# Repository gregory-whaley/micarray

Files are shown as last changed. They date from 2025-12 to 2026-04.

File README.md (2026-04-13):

# MicArray
Multichannel USB microphone for Raspbery Pi Pico for use in acoustic array beamforming.

This C code and PIO code will accept I2S data from two MEMS microphones and create a USB 2.0 audio microphone source with two channels intially, and expandable to more channels in later versions.  The target MCU is the Raspberry Pi RP2040 on the Pico board and the target microphone is the Invensense ICS-43434 MEMS microphone with I2S interface.  The code supports the following features:

- USB 2.0 device enumerates as a standard audio class 2.0 isochronous streaming device.  No host driver installation is necessary for Windows/Mac/Linux.
- Audio sample rate is fixed at 48000 Hz.
- Data is encoded as PCM samples SE_32 (32 bits per sample).
- Audio volume (gain) is fixed and so volume control must be performed at the host application level.
- MEMS microphone interface is I2S with both outputs interleaved into one data path.
- Target MEMS microphone is Invensense ICS-43434, 24 bits/sample.
- Uses Raspberry Pi Pico RP2040 development board.
- USB enumeration of HID interface providing MCU (environment) temperature and microphone separation distance which are important for acoustic beamforming calculations.

## Documentation

### Hardware
The system can be constructed using a Raspberry Pi Pico development board and two MEMS microphone evaluation boards from Adafruit (Part #6049) as shown in the following diagram.
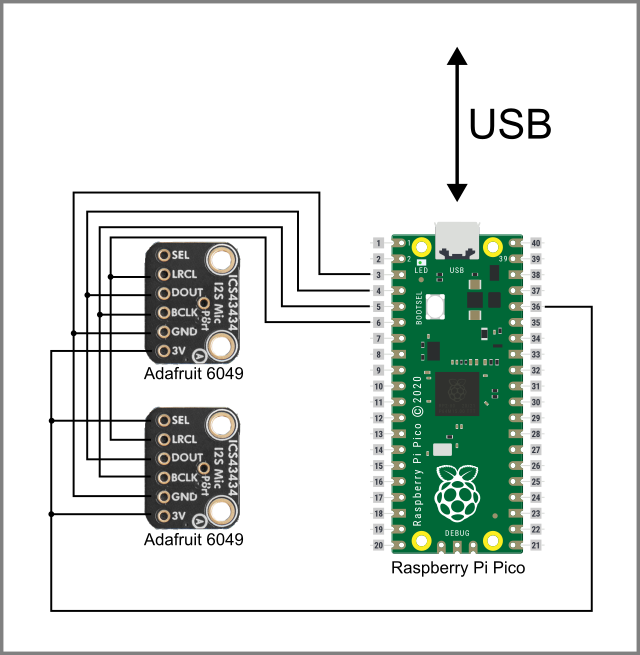
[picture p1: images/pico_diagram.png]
Connection Diagram for Dual Microphones
  Connection Diagram for Dual Microphones

### Supported Boards
- Raspberry Pi Pico/W (RP2040)
- Adafruit #6049 MEMS microphone evaluation board

### Building and Installing

The code is built using the standard [Raspberry Pi Pico SDK](https://github.com/raspberrypi/pico-sdk) and leverages the [TinyUSB library](https://github.com/hathach/tinyusb) for usb functions.

Instructions for installing the Pico development SDK [can be found here](https://rptl.io/pico-get-started).

Clone this repo to a new folder in your local system.
```shell
mkdir micarray
git clone https://github.com/gregory-whaley/micarray.git
```

Unfortunately the version of TinyUSB which is automatically included with the Pico SDK has a buffer allocation error in streaming audio.  This error has been fixed in version 0.19.0, so we must instead clone the current TinyUSB repository also to a separate folder in your local system.
```shell
mkdir tinyusb
git clone https://github.com/hathach/tinyusb.git
```

  The CMakeLists.txt file in the micarray repo includes a redirection to this updated local TinyUSB folder, and so you must edit the following line to point cmake to your local TinyUSB folder.
```
set(PICO_TINYUSB_PATH "/home/YOUR_LOCAL_FOLDER/tinyusb")
```

The code is built from the linux command line as follows:
```shell
cd YOUR_LOCAL_FOLDER/micarray
mkdir build
cd build
cmake .. -DBOARD=raspberry_pi_pico
make
```
which will produce a *.uf2 binary output file in the build folder.  Then follow the standard process to flash the file to the pico by plugging in the pico with the bool_sel button pressed, and copy the uf2 file to the pico folder which is mounted to the system.  After flashing, the pico will present both a standard audio streaming USB interface, and an HID interface.  The audio function can be tested using any recording application such as Audacity.  The hid_test.py script can be used to query the HID functions which returns the pico device temperature and a (hard coded) number representing the physical distance between microphones in the array.  In linux HID devices are owned by root by default and thus blocked from user access, so the simplest method to run the python script is to run as root.

### Custom PCB
A printed circuit board was designed for this system to support two microphones at a fixed spacing which is important for beamforming use.  KiCAD PCB files are included herein.  In this case the microphone access ports are 390 mm apart.
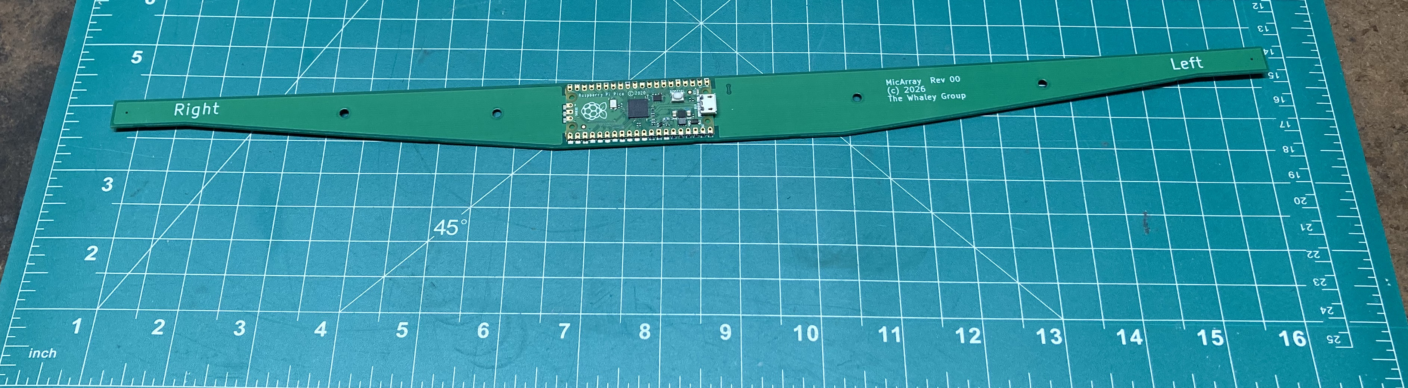
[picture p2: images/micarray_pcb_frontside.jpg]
Custom PCB of two microphone sensor
Custom PCB of two microphone sensor

### Weather Tolerant Enclosure
A mechanical cover for this circuit board was designed and built where almost the entire board is coated in polyurethane to allow for use outdoors for long term sensing.
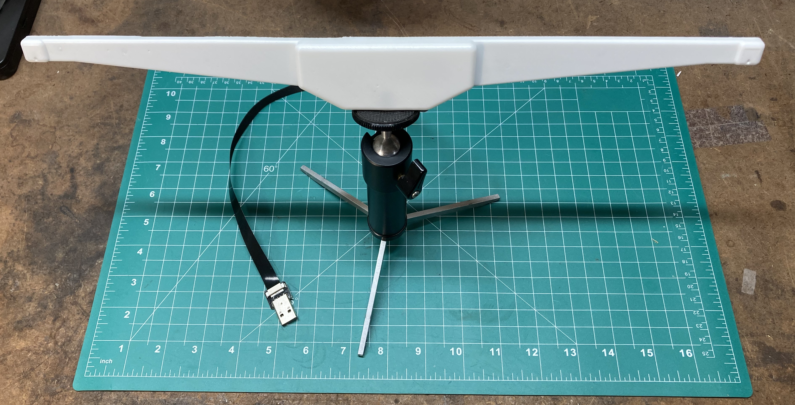
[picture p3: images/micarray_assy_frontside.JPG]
MicArray sensor with polyurethane coating
MicArray sensor with polyurethane coating

A 3D model was designed for the enclosure and was printed in SLS resin to serve as a form for generating a silicone mold.  The PCB is then placed in the finished mold and liquid polyurethane is poured in the mold to completely embed the PCB within the polyurethane except for the two small microphone access ports.  The microphone ports are angled at 45 degrees from vertical to ensure rainwater will not ingress into the ports.  A flat flexible USB cable was chosen to connect the microphone so that the cable may fit under a weather seal such as in a window frame or under a gasket in a sealed enclosure.  This allows the host computer to communicate with the microphones from a dry environment.

## License
The MIT License (MIT)

Copyright (C) 2025 The Whaley Group

Permission is hereby granted, free of charge, to any person obtaining a copy of this software and associated documentation files (the 'Software'), to deal in the Software without restriction, including without limitation the rights to use, copy, modify, merge, publish, distribute, sublicense, and/or sell copies of the Software, and to permit persons to whom the Software is furnished to do so, subject to the following conditions:

The above copyright notice and this permission notice shall be included in all copies or substantial portions of the Software.

THE SOFTWARE IS PROVIDED 'AS IS', WITHOUT WARRANTY OF ANY KIND, EXPRESS OR IMPLIED, INCLUDING BUT NOT LIMITED TO THE WARRANTIES OF MERCHANTABILITY, FITNESS FOR A PARTICULAR PURPOSE AND NONINFRINGEMENT. IN NO EVENT SHALL THE AUTHORS OR COPYRIGHT HOLDERS BE LIABLE FOR ANY CLAIM, DAMAGES OR OTHER LIABILITY, WHETHER IN AN ACTION OF CONTRACT, TORT OR OTHERWISE, ARISING FROM, OUT OF OR IN CONNECTION WITH THE SOFTWARE OR THE USE OR OTHER DEALINGS IN THE SOFTWARE.

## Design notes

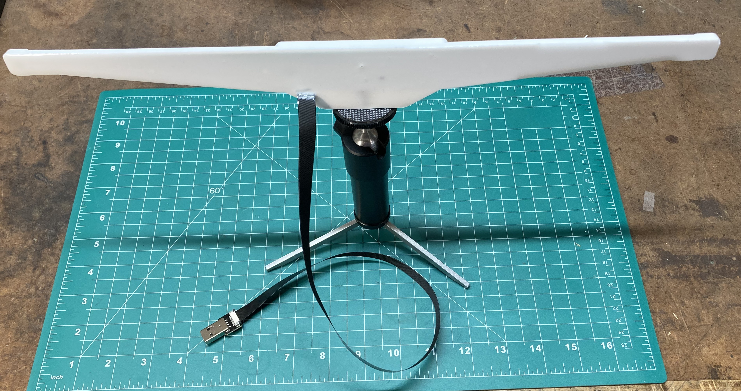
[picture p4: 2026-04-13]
images/micarray_assy_backside.JPG

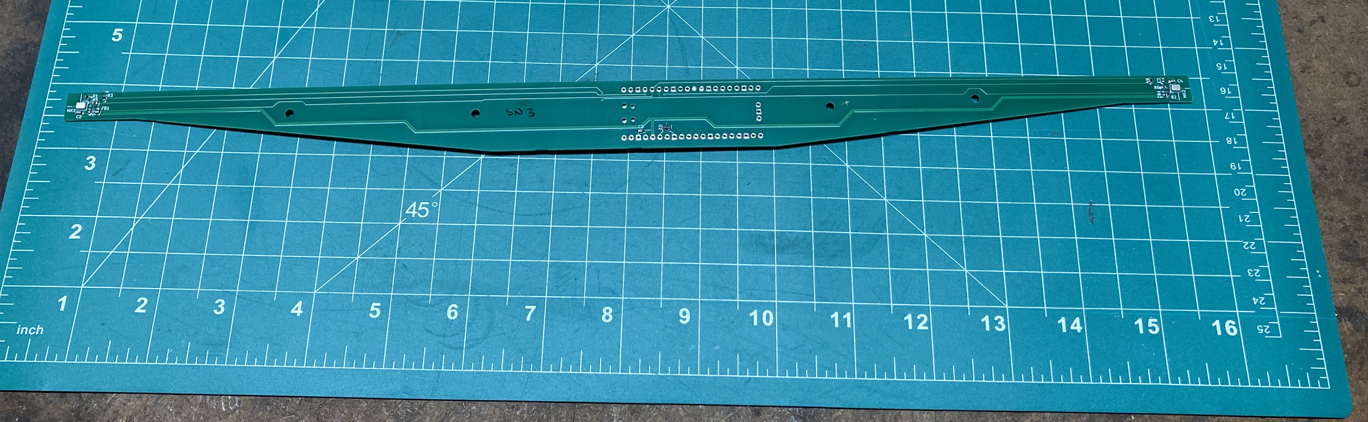
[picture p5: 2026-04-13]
images/micarray_pcb_backside.jpg

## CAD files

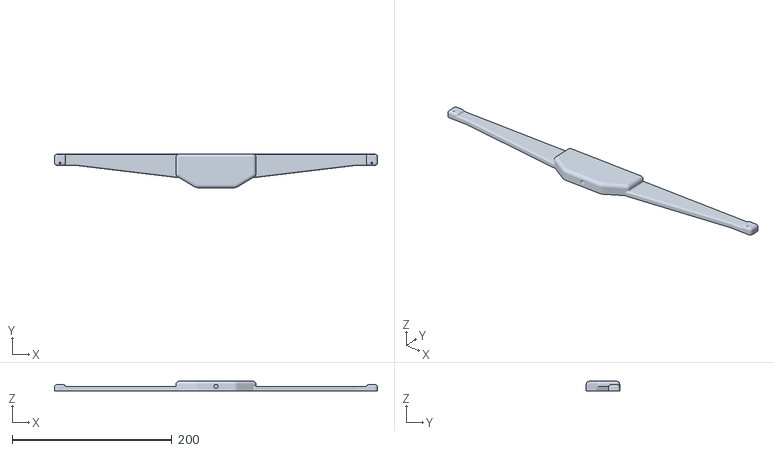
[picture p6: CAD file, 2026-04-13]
mechanical/MicArray_03_export.stl
404.0 x 42.0 x 12.0

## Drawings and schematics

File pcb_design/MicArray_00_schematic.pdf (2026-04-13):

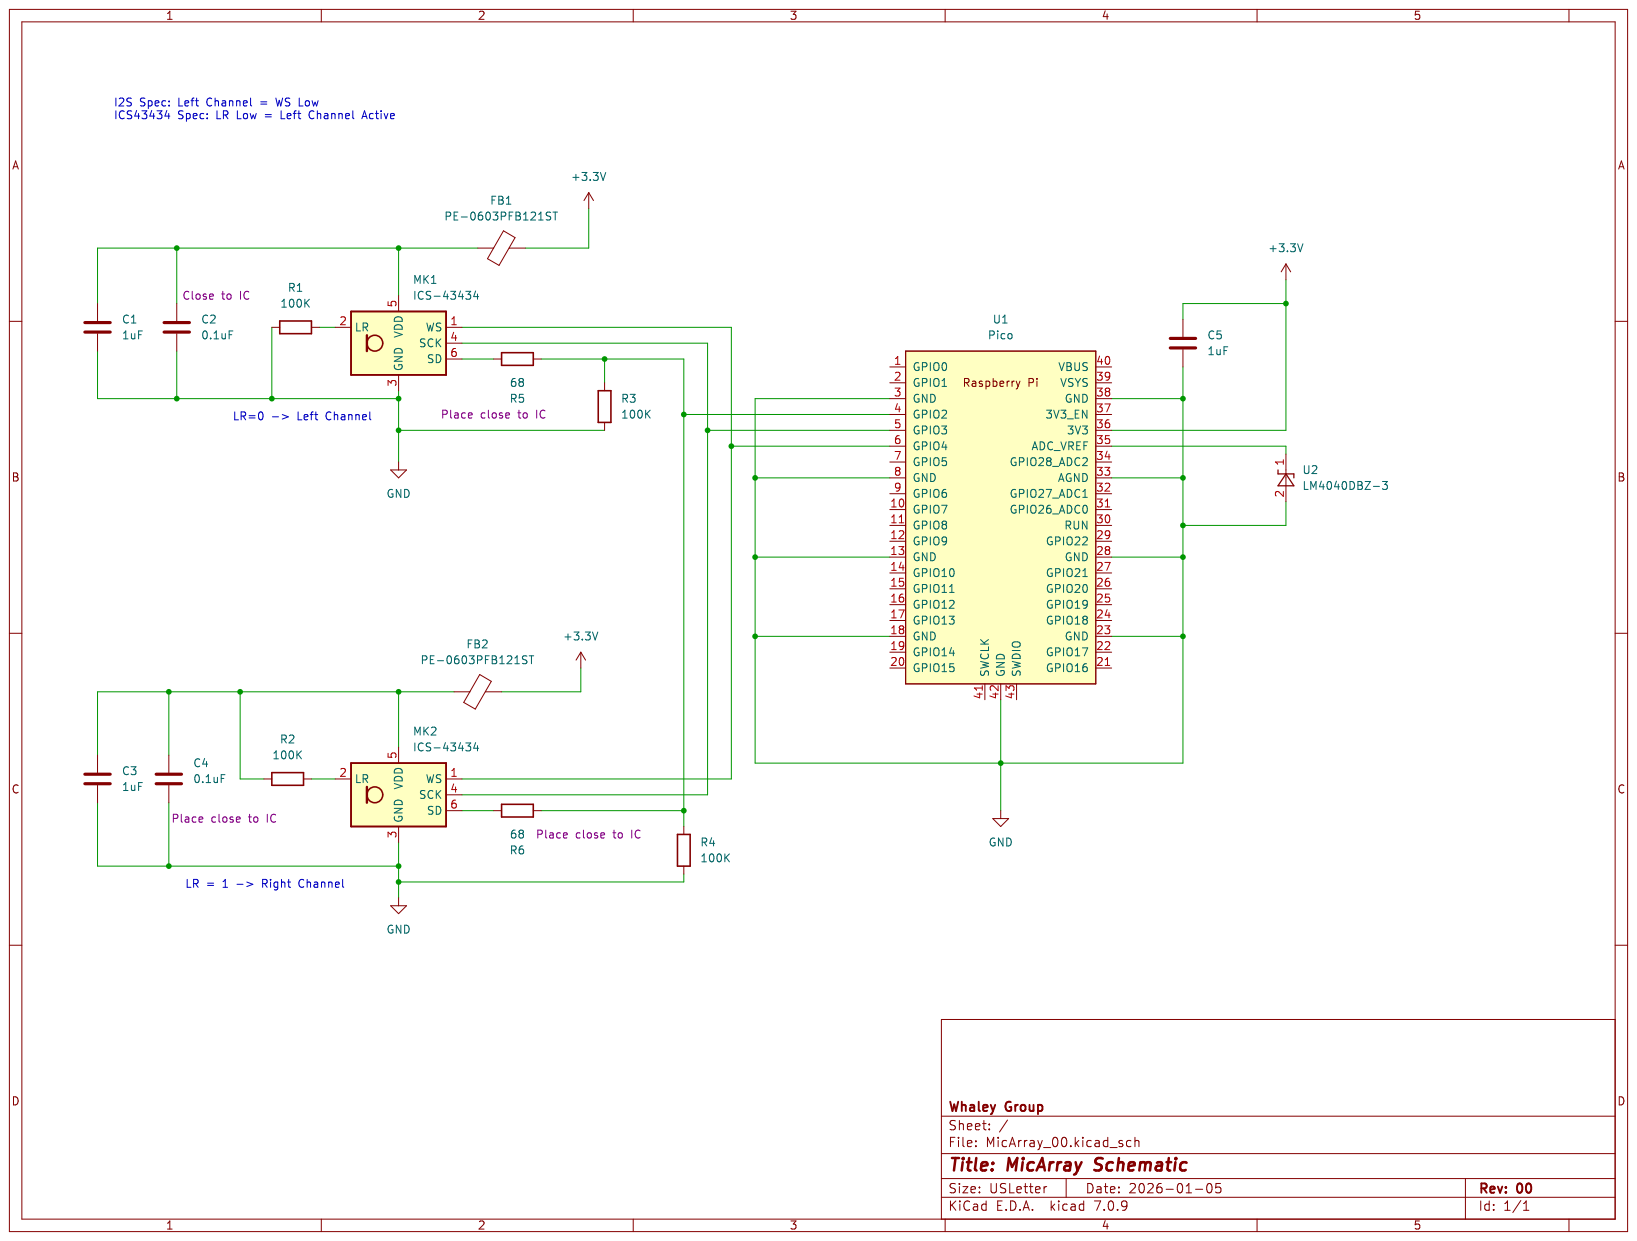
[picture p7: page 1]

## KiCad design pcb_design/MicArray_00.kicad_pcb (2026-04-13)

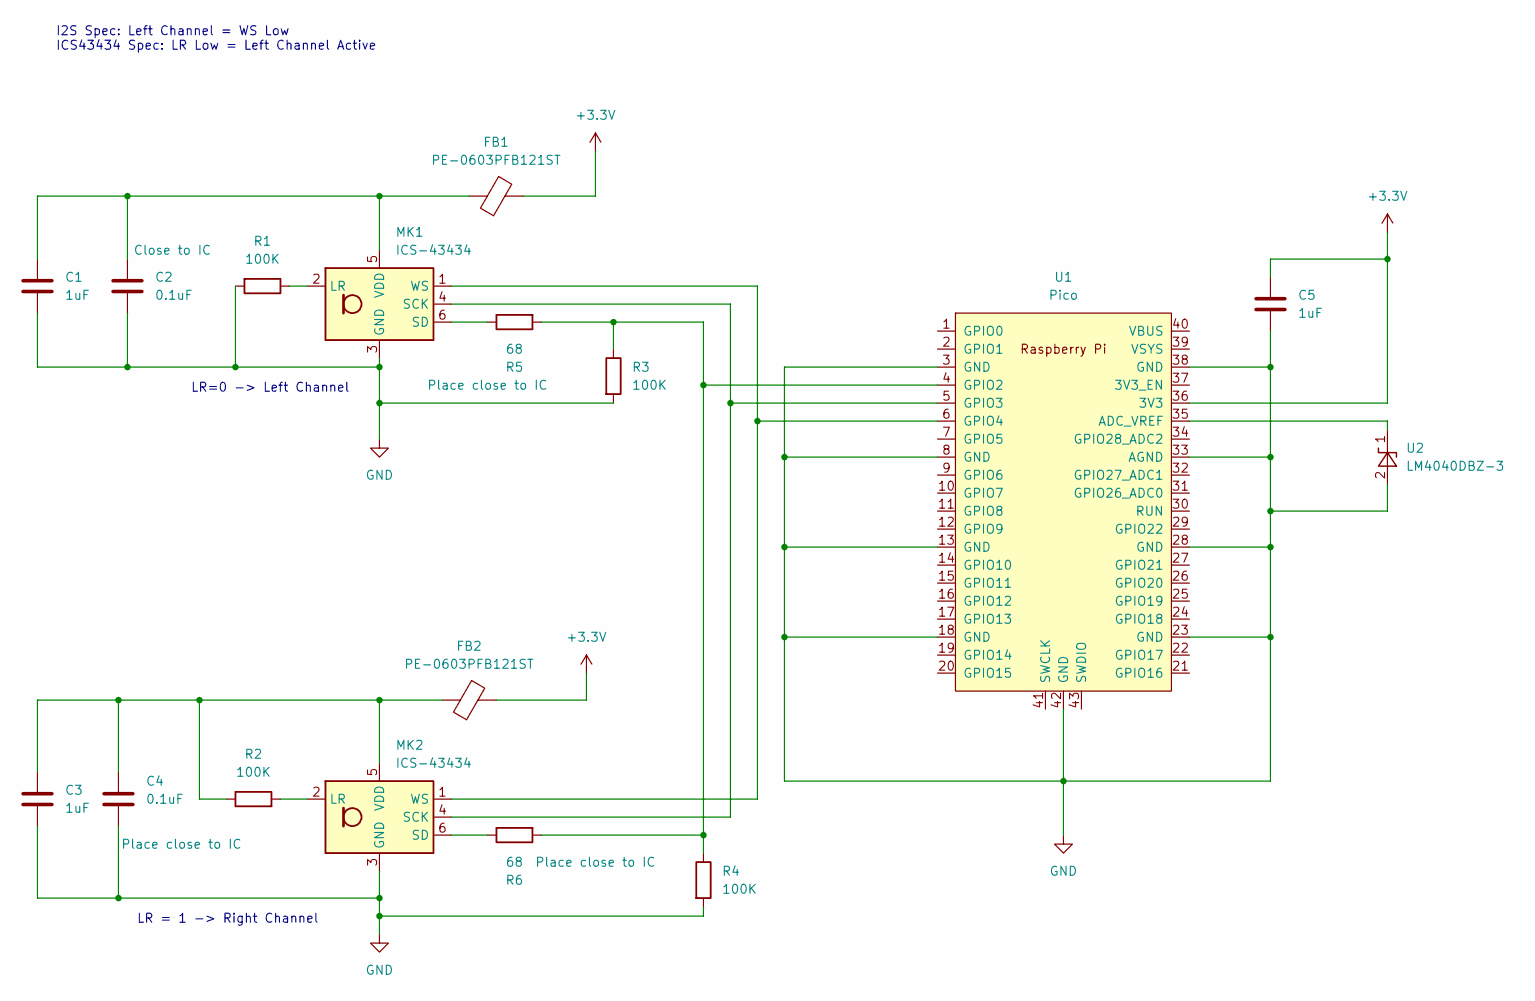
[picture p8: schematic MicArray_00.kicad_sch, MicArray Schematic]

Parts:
C1, C3, C5: 1uF; C_0603_1608Metric_Pad1.08x0.95mm_HandSolder
C2, C4: 0.1uF; C_0603_1608Metric_Pad1.08x0.95mm_HandSolder
FB1, FB2: PE-0603PFB121ST; C_0603_1608Metric_Pad1.08x0.95mm_HandSolder
MK1, MK2: ICS-43434; InvenSense_ICS-43434-6_3.5x2.65mm
R1, R2, R3, R4: 100K; R_0603_1608Metric_Pad0.98x0.95mm_HandSolder
R5, R6: 68; R_0603_1608Metric_Pad0.98x0.95mm_HandSolder
U1: Pico; RPi_Pico_SMD_TH
U2: LM4040DBZ-3; SOT-23

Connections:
+3.3V: C5.1, FB1.2, FB2.2, U1.36 (3V3)
GND: C1.2, C2.2, C3.2, C4.2, C5.2, MK1.3 (GND), MK2.3 (GND), R1.2, R3.2, R4.2, U1.3 (GND), U1.8 (GND), U1.13 (GND), U1.18 (GND), U1.23 (GND), U1.28 (GND), U1.33 (AGND), U1.38 (GND), U1.42 (GND), U2.2 (A)
unnamed: MK1.2 (LR), R1.1
unnamed: MK1.4 (SCK), MK2.4 (SCK), U1.5 (GPIO3)
unnamed: MK1.6 (SD), R5.1
unnamed: C1.1, C2.1, FB1.1, MK1.5 (VDD)
unnamed: MK1.1 (WS), MK2.1 (WS), U1.6 (GPIO4)
unnamed: MK2.2 (LR), R2.2
unnamed: MK2.6 (SD), R6.1
unnamed: C3.1, C4.1, FB2.1, MK2.5 (VDD), R2.1
unnamed: U1.35 (ADC_VREF), U2.1 (K)
unnamed: R3.1, R4.1, R5.2, R6.2, U1.4 (GPIO2)

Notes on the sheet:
LR = 1 -> Right Channel
LR=0 -> Left Channel
I2S Spec: Left Channel = WS Low ICS43434 Spec: LR Low = Left Channel Active

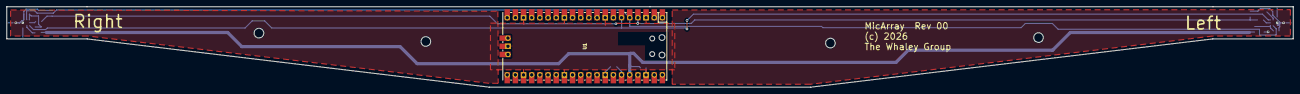
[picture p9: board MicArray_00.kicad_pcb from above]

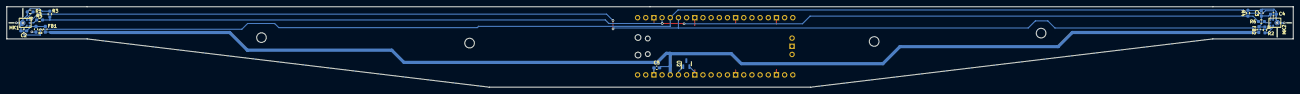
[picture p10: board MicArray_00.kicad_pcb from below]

Board: 2 copper layers, 400.0 x 25.0 mm, 17 parts (16 on the bottom side), 12 nets.

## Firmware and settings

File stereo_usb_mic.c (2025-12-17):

/*
 * The MIT License (MIT)
 *
 * Copyright (C) 2025 The Whaley Group
 * 
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
 *
 *


    Pi Pico implementation of a USB 2.0 interface to multiple MEMS microphones.
    G. Whaley
    22 Oct 2025

    Functions as usb 2.0 interface to two or more MEMS microphones for the
    purpose of acoustic beamforming applications.

    Functional Specifications:
    - USB 2.0 device enumerates as a standard audio class 2.0 device.
    - Audio sample rate is fixed at 48000 Hz.
    - Data is encoded as PCM samples SE_32 (32 bits per sample).
    - MEMS microphones output I2S data interface.
    - Target MEMS microphone is Invensense ICS-43434, 24 bits/sample
    - Uses Raspberry Pi Pico RP2040 microcontroller.
    - USB enumeration of HID interface providing MCU temperature.

    Codebase uses the TinyUSB library.  Note the version of Tinyusb supplied
    with the Pico SDK has an endpoint buffer bug, which has been fixed in
    Tinyusb version 0.19.0 and later so this code does not reference the
    SDK version.
*/


#include <stdio.h>
#include "pico/stdlib.h"
#include "stereo_mic_i2s.c"
#include "usb_mic_callbacks.h"
#include "hardware/adc.h"
#include "bsp/board_api.h"


const struct microphone_config mic_config = {
    .gpio_data = 2,                         // GPIO pin for the I2S DAT signal
    .gpio_clk = 3,                          // GPIO pin for the I2S CLK signal
    .pio = pio0,                            // PIO instance to use
    .pio_sm = 0,                            // PIO State Machine instance to use
};

int decimate = 0;


int main()
{
    stdio_init_all();                                   //  supports standard uart output for printf.
    i2s_microphone_init(mic_config);
    i2s_microphone_start(mic_config);
    usb_microphone_init();                              // contains tusb_init()

    adc_init();
    adc_select_input(4);                                //  chan 4 is the internal temperature sensor
    adc_set_temp_sensor_enabled(true);                  // activate the internal pullup resistor to bias temp sensor
    board_init();
    board_led_write(1);                                 // turn on LED for USB power indicator


    while (true) {
        while (sample_buffer_ready == 0) {     // sample_buffer_ready changes in the background and is volatile
            tud_task();                         // spend most time here polling for usb tasks
        }  
                                                                    //  at this point we have a i2s buffer full to process    
        usb_microphone_write(sample_buffer, sizeof(sample_buffer));  // Write local buffer to the USB microphone
                                                                    // sample_buffer is array of interleaved 32bit ints.
                                                                    // size is number of bytes.
        sample_buffer_ready = false;
    }
};

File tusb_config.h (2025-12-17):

/*
 * The MIT License (MIT)
 *
 * Copyright (C) 2025 The Whaley Group
 *
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
 */

#ifndef _TUSB_CONFIG_H_
#define _TUSB_CONFIG_H_

#ifdef __cplusplus
extern "C" {
#endif

//--------------------------------------------------------------------
// COMMON CONFIGURATION
//--------------------------------------------------------------------

// defined by compiler flags for flexibility
#ifndef CFG_TUSB_MCU
#error "CFG_TUSB_MCU must be defined"
#endif

#if CFG_TUSB_MCU == OPT_MCU_LPC43XX || CFG_TUSB_MCU == OPT_MCU_LPC18XX || CFG_TUSB_MCU == OPT_MCU_MIMXRT10XX
#define CFG_TUSB_RHPORT0_MODE       (OPT_MODE_DEVICE | OPT_MODE_HIGH_SPEED)
#else
#define CFG_TUSB_RHPORT0_MODE       OPT_MODE_DEVICE
#endif

#ifndef CFG_TUSB_OS
#define CFG_TUSB_OS                 OPT_OS_NONE
#endif

#ifndef CFG_TUSB_DEBUG
#define CFG_TUSB_DEBUG              0
#endif

// CFG_TUSB_DEBUG is defined by compiler in DEBUG build
//#define CFG_TUSB_DEBUG           2

/* USB DMA on some MCUs can only access a specific SRAM region with restriction on alignment.
 * Tinyusb use follows macros to declare transferring memory so that they can be put
 * into those specific section.
 * e.g
 * - CFG_TUSB_MEM SECTION : __attribute__ (( section(".usb_ram") ))
 * - CFG_TUSB_MEM_ALIGN   : __attribute__ ((aligned(4)))
 */
#ifndef CFG_TUSB_MEM_SECTION
#define CFG_TUSB_MEM_SECTION
#endif

#ifndef CFG_TUSB_MEM_ALIGN
#define CFG_TUSB_MEM_ALIGN          __attribute__ ((aligned(4)))
#endif

//--------------------------------------------------------------------
// DEVICE CONFIGURATION
//--------------------------------------------------------------------

#ifndef CFG_TUD_ENDPOINT0_SIZE
#define CFG_TUD_ENDPOINT0_SIZE    64
#endif

//------------- CLASS -------------//
//  The following shows the number of interfaces for each class.
#define CFG_TUD_CDC               0
#define CFG_TUD_MSC               0
#define CFG_TUD_HID               1
#define CFG_TUD_MIDI              0
#define CFG_TUD_AUDIO             1
#define CFG_TUD_VENDOR            0

//--------------------------------------------------------------------
// AUDIO CLASS DRIVER CONFIGURATION
//--------------------------------------------------------------------

// Have a look into audio_device.h for all configurations
// The stereo microphone has one audio function so we populate values for FUNC_1
// We need to define the size of the function 1 descriptor and the descriptor itself for two 
// microphone channels.  TUSB only has prototype definitions for 1 and 4 channels, 
// so the 2 channel definitions are here.

#define TUD_AUDIO_DESC_FEATURE_UNIT_TWO_CHANNEL_MUTEONLY_LEN (6+(2+1)*4)
#define TUD_AUDIO_DESC_FEATURE_UNIT_TWO_CHANNEL_MUTEONLY(_unitid, _srcid, _ctrlch0master, _ctrlch1, _ctrlch2, _stridx) \
		TUD_AUDIO_DESC_FEATURE_UNIT_TWO_CHANNEL_MUTEONLY_LEN, TUSB_DESC_CS_INTERFACE, AUDIO20_CS_AC_INTERFACE_FEATURE_UNIT, _unitid, _srcid, U32_TO_U8S_LE(_ctrlch0master), U32_TO_U8S_LE(_ctrlch1), U32_TO_U8S_LE(_ctrlch2), _stridx



#define TUD_AUDIO_MIC_TWO_CH_DESC_LEN (TUD_AUDIO20_DESC_IAD_LEN\
  + TUD_AUDIO20_DESC_STD_AC_LEN\
  + TUD_AUDIO20_DESC_CS_AC_LEN\
  + TUD_AUDIO20_DESC_CLK_SRC_LEN\
  + TUD_AUDIO20_DESC_INPUT_TERM_LEN\
  + TUD_AUDIO20_DESC_OUTPUT_TERM_LEN\
  + TUD_AUDIO_DESC_FEATURE_UNIT_TWO_CHANNEL_MUTEONLY_LEN\
  + TUD_AUDIO20_DESC_STD_AS_LEN\
  + TUD_AUDIO20_DESC_STD_AS_LEN\
  + TUD_AUDIO20_DESC_CS_AS_INT_LEN\
  + TUD_AUDIO20_DESC_TYPE_I_FORMAT_LEN\
  + TUD_AUDIO20_DESC_STD_AS_ISO_EP_LEN\
  + TUD_AUDIO20_DESC_CS_AS_ISO_EP_LEN)
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

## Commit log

2025-12-16 data is flowing but not correct values.
    [stereo_mic_i2s.c, stereo_usb_mic.c]
2025-12-16 valid I2S data flow confirmed!
2025-12-16 first compile and usb data flow verified. sample rate is offhowever.
2025-12-16 first error free usb initialization!!
    [stereo_mic_i2s.c, tusb_config.h]
2025-12-16 Compiles and usb device enumerates properly however fails to transfer iso samples due to EP conflict. Seems to be a TUSB bug.
    [stereo_usb_mic.c, tusb_config.h]
2025-12-16 compiles and enumerates without error using updated tinyusb repo. Some streaming observed for the first time!!
    [tusb_config.h]
2025-12-16 runs for first time without missing or extra samples on one channel. Tinyusb driver uses no explicit flow control and has a 4X input buffer for the EP.
    [tusb_config.h]
2025-12-16 commit of functioning device before HID code inserted.
2025-12-16 Added some introductory comments, the MIT license, and set the LED on the board to indicate power on.
2025-12-17 updated USB VID and PID allocated by Raspberry Pi Foundation. Updated MIT license text.
2026-03-21 updated descriptors for serial number string reflecting the PCB number, and updating the temperature moeasurement code in hid callback to use the 3.00V reference in the calculation, and set the mic d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
2026-04-13 Included electrical and mechanical design files and updated the README file.
    [MicArray_00.kicad_pcb, MicArray_00.kicad_sch, MicArray_03_export.stl]

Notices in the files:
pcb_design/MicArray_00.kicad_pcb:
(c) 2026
